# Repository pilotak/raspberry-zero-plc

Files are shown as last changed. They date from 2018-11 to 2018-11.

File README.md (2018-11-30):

# Raspberry Pi Zero/W based PLC
DIN mount PLC with following features
- power supply 7-45V DC
- 2x SPDT relay
- 1x SSR relay output (positive)
- 4x mosfet output (negative)
- 4x opto-isolated digital inputs with hardware debounce
- 3x analog input + 1 additional for power supply monitoring
- 1x CAN interface
- 1x RS232 (can be used for console or as standalone serial port)

## Picture
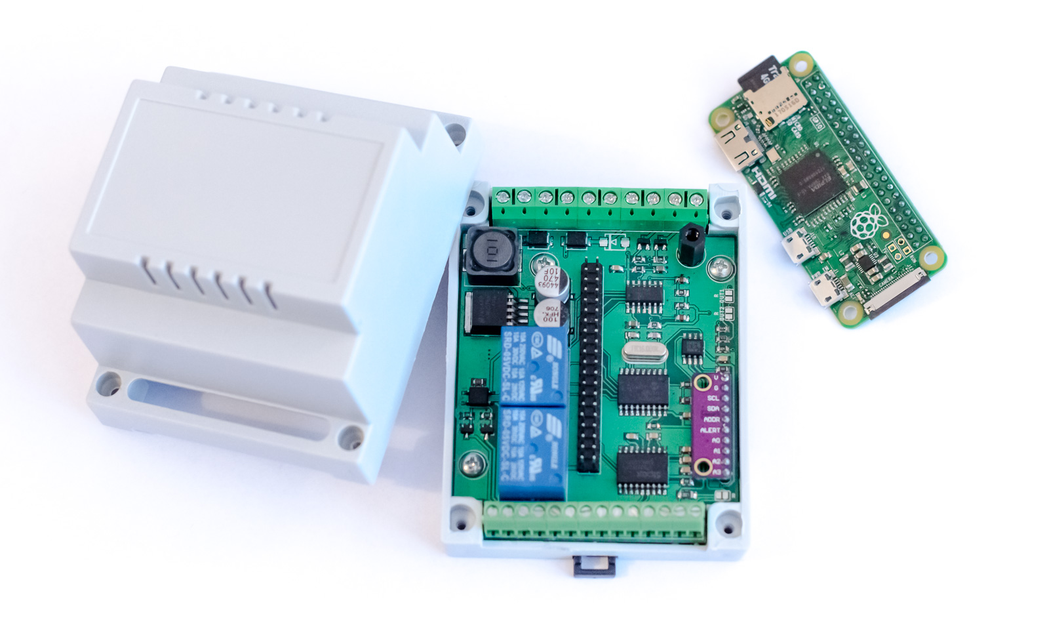
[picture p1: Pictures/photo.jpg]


## BOM

| Qty | Component | Value | Package |
|:---:| --- | ----- | --- |
| 4 | Capacitor | 1uF/6.3V | C0805 |
| 2 | Capacitor | 10uF/6.3V | C0805 |
| 2 | Capacitor | 22p | C0805 |
| 12 | Capacitor | 100n | C0805 |
| 1 | Capacitor | 100uF/50V | PANASONIC_E |
| 1 | Capacitor | 470uF/10V | PANASONIC_E |
| 6 | Diode | S1B | DO214AC (SMA) |
| 1 | TVS | SMBJ33 | DO214AA (SMB) |
| 2 | Shottky diode| SS26 | DO214AA (SMB) |
| 1 | NAND Schmitt trigger | 74HC132D | SO14 |
| 1 | CAN controller | MCP2515-I/SO | SO-18L |
| 1 | RS232 driver | SP3222EET | SO-18L |
| 1 | CAN transceiver | TJA1050 | SO08 |
| 4 | Photocoupler | TLP185 | SOP04 |
| 1 | SSR relay | AQY212S | SOP04 |
| 2 | Realy | SRD-5VDC-SL-C | |
| 1 | Inductor | DE1207-100 | DR125 |
| 4 | N-mosfet | 2N7002 | SOT23 |
| 1 | Crystal | 16MHz | HC49U-V |
| 2 | PNP transistor | BCX71SMD | SOT23 |
| 1 | P-mosfet | DMG2305UX | SOT23 |
| 2 | N-mosfet | IRLML0060TRPBF | SOT23 |
| 5 | Resistor| 1K | R0805 |
| 5 | Resistor| 2K2 | R0805 |
| 4 | Resistor| 10K | R0805 |
| 1 | Resistor| 18K | R0805 |
| 3 | Resistor| 47K | R0805 |
| 4 | Resistor| 68K | R0805 |
| 6 | Resistor| 100K | R0805 |
| 1 | Resistor| 120R | R1206 |
| 4 | Resistor| 820K | R0805 |
| 1 | ADC | ADS1015 | module |
| 1 | LDO regulator | LM1117-3.3 | SOT223 |
| 1 | Step-down regulator | LM2576-5.0 | TO-263-5 |
| 1 | Raspberry Pi | Zero | |
| 2 | Screw terminal| KF301-5.0-2P | KF301-5.0-2P |
| 2 | Screw terminal| KF301-5.0-3P | KF301-5.0-3P |
| 7 | Screw terminal| KF350-3.5-2P | KF350-3.50-2P |
| 1 | DIN case | Z100J PS | |

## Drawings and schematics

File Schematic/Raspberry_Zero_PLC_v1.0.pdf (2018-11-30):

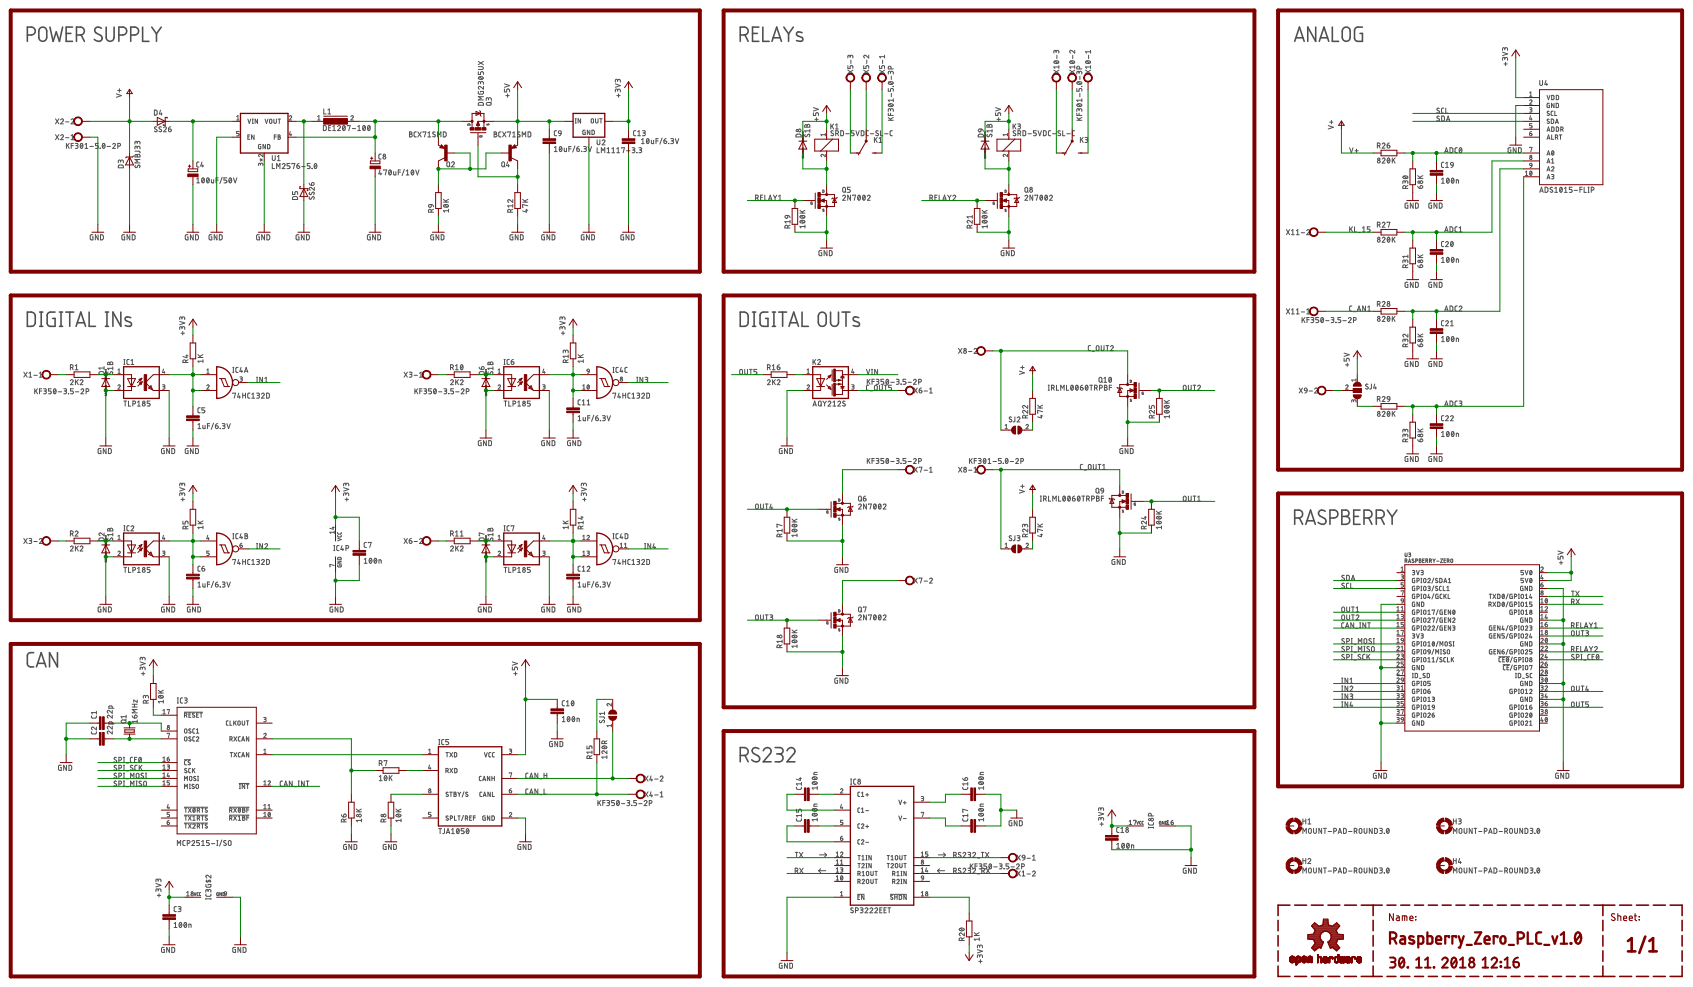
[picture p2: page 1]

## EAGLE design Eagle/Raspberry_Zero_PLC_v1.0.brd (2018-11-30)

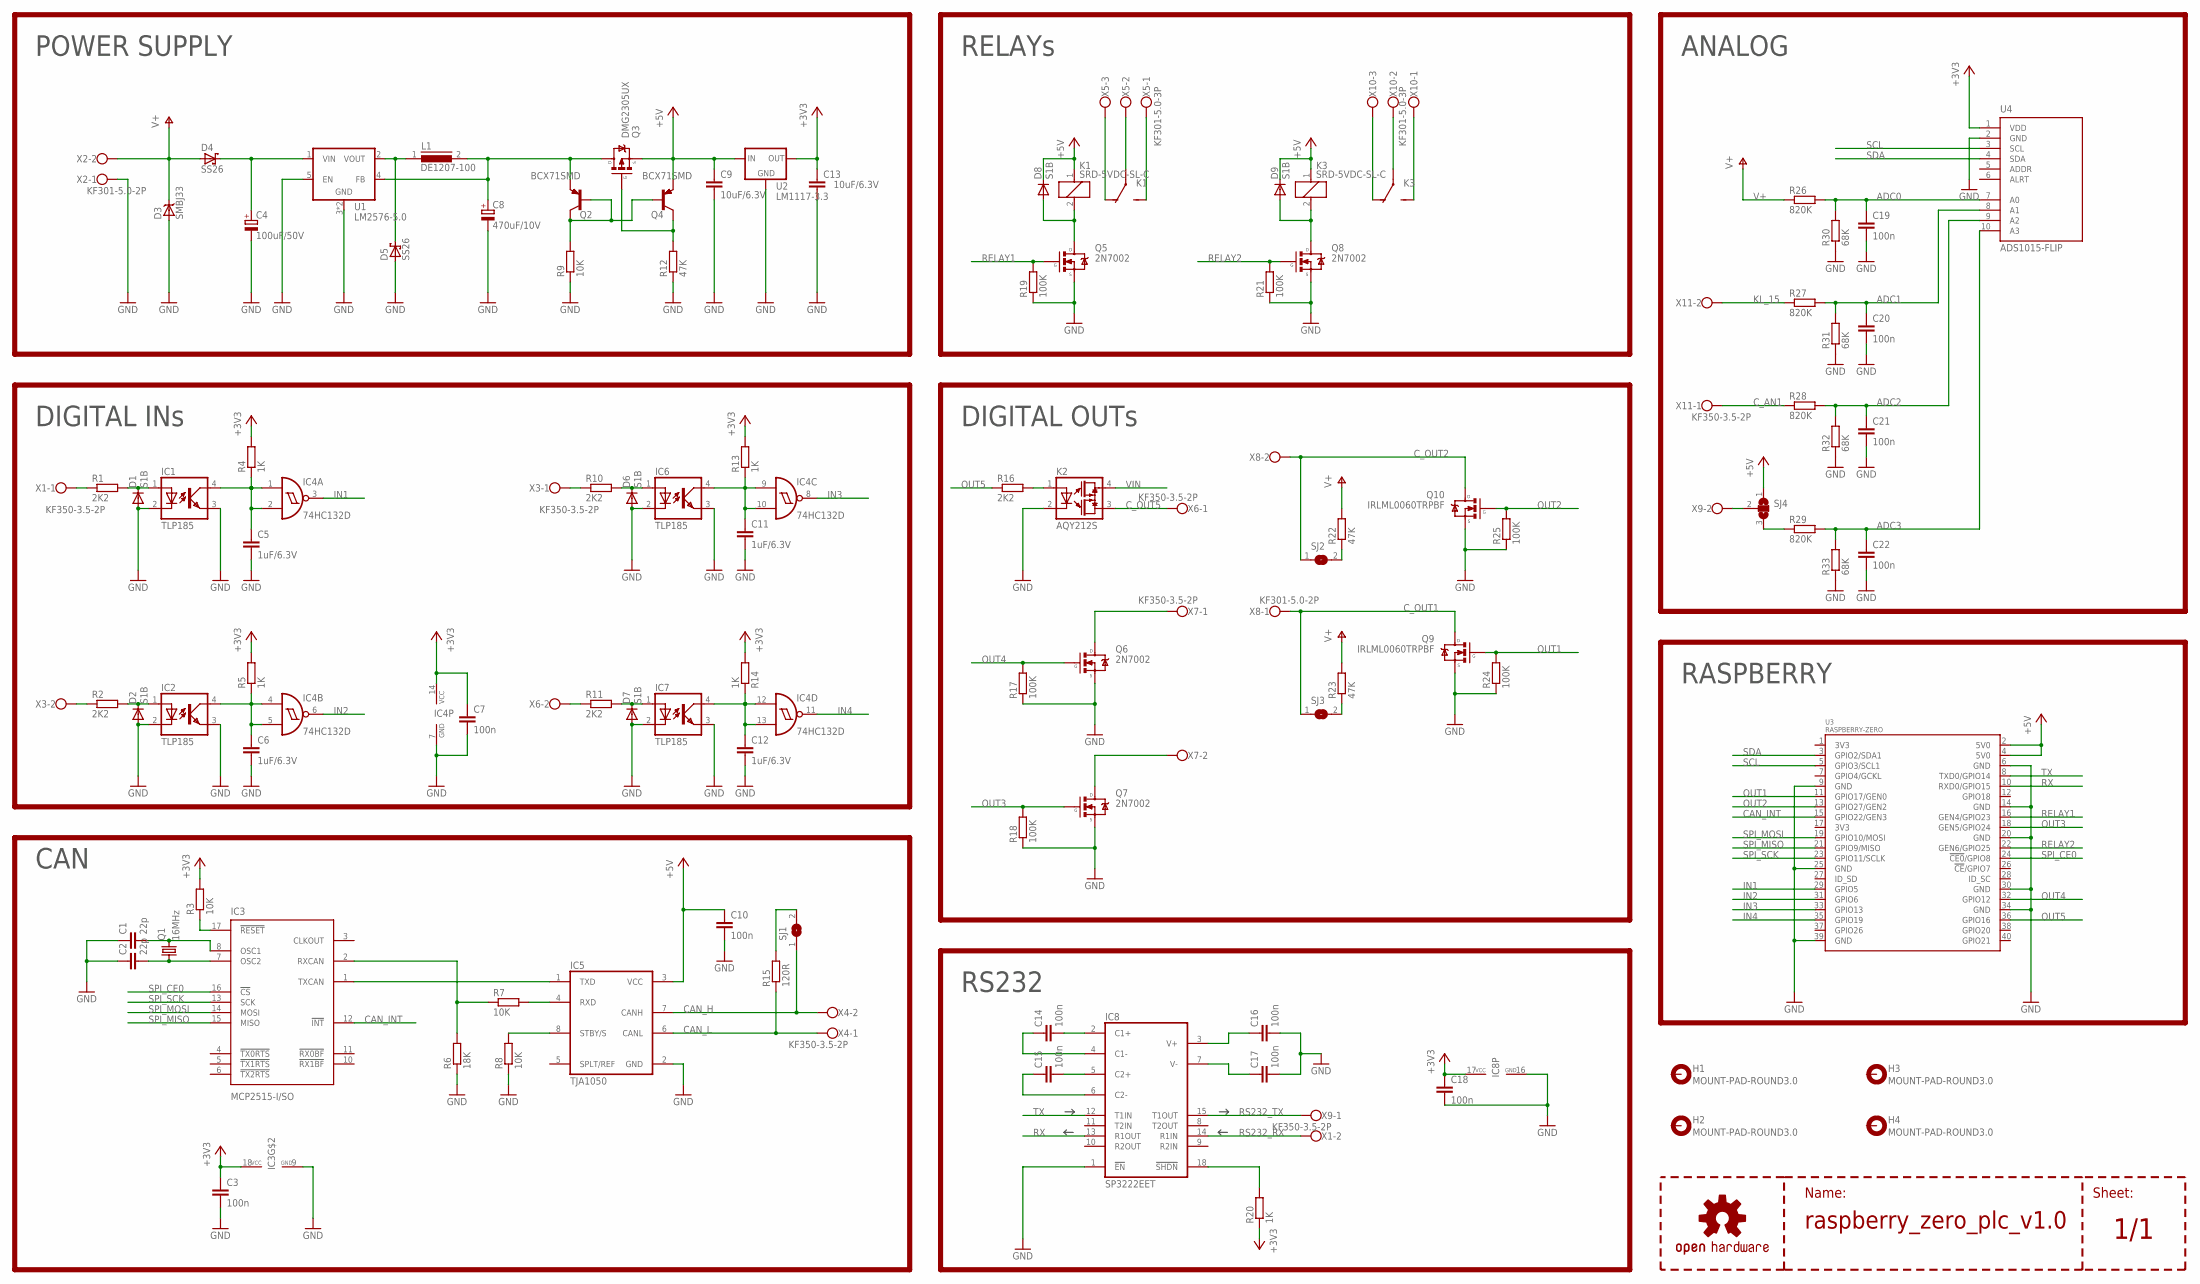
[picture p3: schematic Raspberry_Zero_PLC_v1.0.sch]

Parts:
C1, C2: 22p; C0805
C3, C7, C10, C14, C15, C16, C17, C18, C19, C20, C21, C22: 100n; C0805
C4: 100uF/50V; PANASONIC_E
C5, C6, C11, C12: 1uF/6.3V; C0805
C8: 470uF/10V; PANASONIC_E
C9, C13: 10uF/6.3V; C0805
D1, D2, D6, D7, D8, D9: S1B; DO214AC
D3: SMBJ33; DO214AA
D4, D5: SS26; DO214AA
H1, H2, H3, H4: MOUNT-PAD-ROUND3.0; 3,0-PAD
IC1, IC2, IC6, IC7: TLP185; SOP04
IC3: MCP2515-I/SO; SO-18L
IC4: 74HC132D; SO14
IC5: TJA1050; SO08
IC8: SP3222EET; SO-18L
K1, K3: SRD-5VDC-SL-C; SRD
K2: AQY212S; SOP04
L1: DE1207-100; DR125
LOGO1: OSHW-LOGOM-COPPER; OSHW-LOGO-M_COPPER
Q1: 16MHz; HC49U-V
Q2, Q4: BCX71SMD; SOT23
Q3: DMG2305UX; SOT23
Q5, Q6, Q7, Q8: 2N7002; SOT23
Q9, Q10: IRLML0060TRPBF; SOT23
R1, R2, R10, R11, R16: 2K2; R0805
R3, R7, R8, R9: 10K; R0805
R4, R5, R13, R14, R20: 1K; R0805
R6: 18K; R0805
R12, R22, R23: 47K; R0805
R15: 120R; R1206
R17, R18, R19, R21, R24, R25: 100K; R0805
R26, R27, R28, R29: 820K; R0805
R30, R31, R32, R33: 68K; R0805
SJ1, SJ2, SJ3: SJ
SJ4: SJ2W; SJ_2
U1: LM2576-5.0; TO-263-5
U2: LM1117-3.3; SOT223
U3: RASPBERRY-ZERO; RASPBERRYPI_ZERO
U4: ADS1015-FLIP; ADS1115-_FLIP
X1, X3, X4, X6, X7, X9, X11: KF350-3.5-2P; KF350-3.50-2P
X2, X8: KF301-5.0-2P
X5, X10: KF301-5.0-3P

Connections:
+3V3: C3.1, C7.1, C13.1, C18.1, IC3.18 (VCC), IC4.14 (VCC), IC8.17 (VCC), R3.2, R4.2, R5.2, R13.2, R14.2, R20.1, U2.2 (OUT), U2.4 (OUT), U4.1 (VDD)
+5V: C9.1, C10.1, D8.C, D9.C, IC5.3 (VCC), K1.1, K3.1, Q3.2 (S), Q4.2 (E), SJ4.1, U2.3 (IN), U3.2 (5V0), U3.4 (5V0)
ADC0: C19.1, R26.2, R30.2, U4.7 (A0)
ADC1: C20.1, R27.2, R31.2, U4.8 (A1)
ADC2: C21.1, R28.2, R32.2, U4.9 (A2)
ADC3: C22.1, R29.2, R33.2, U4.10 (A3)
CAN_H: IC5.7 (CANH), SJ1.1, X4.2
CAN_INT: IC3.12 (!INT!), U3.15 (GPIO22/GEN3)
CAN_L: IC5.6 (CANL), R15.1, X4.1
C_AN1: R28.1, X11.1
C_AN2/5V: SJ4.2, X9.2
C_IN1: R1.1, X1.1
C_IN2: R2.1, X3.2
C_IN3: R10.1, X3.1
C_IN4: R11.1, X6.2
C_OUT1: Q9.3 (D), SJ3.1, X8.1
C_OUT2: Q10.3 (D), SJ2.1, X8.2
C_OUT3: Q7.3 (D), X7.2
C_OUT4: Q6.3 (D), X7.1
C_OUT5: K2.3 (OUT0), X6.1
GND: C1.1, C2.1, C3.2, C4.-, C5.2, C6.2, C7.2, C8.-, C9.2, C10.2, C11.2, C12.2, C13.2, C16.2, C17.2, C18.2, C19.2, C20.2, C21.2, C22.2, D1.A, D2.A, D3.A, D5.A, D6.A, D7.A, IC1.2 (C), IC1.3 (EMIT), IC2.2 (C), IC2.3 (EMIT), IC3.9 (GND), IC4.7 (GND), IC5.2 (GND), IC6.2 (C), IC6.3 (EMIT), IC7.2 (C), IC7.3 (EMIT), IC8.1 (!EN!), IC8.16 (GND), K2.2 (C), Q5.2 (S), Q6.2 (S), Q7.2 (S), Q8.2 (S), Q9.2 (S), Q10.2 (S), R6.1, R8.1, R9.1, R12.1, R17.1, R18.1, R19.1, R21.1, R24.1, R25.1, R30.1, R31.1, R32.1, R33.1, U1.3 (GND), U1.5 (EN), U1.6 (GND), U2.1 (GND), U3.6 (GND), U3.9 (GND), U3.14 (GND), U3.20 (GND), U3.25 (GND), U3.30 (GND), U3.34 (GND), U3.39 (GND), U4.2 (GND), X2.1
IN1: IC4.3 (O), U3.29 (GPIO5)
IN2: IC4.6 (O), U3.31 (GPIO6)
IN3: IC4.8 (O), U3.33 (GPIO13)
IN4: IC4.11 (O), U3.35 (GPIO19)
KL_15: R27.1, X11.2
unnamed: Q2.1 (B), Q2.3 (C), Q4.1 (B), R9.2
unnamed: Q3.1 (G), Q4.3 (C), R12.2
unnamed: C2.2, IC3.7 (OSC2), Q1.1
unnamed: C8.+, L1.2, Q2.2 (E), Q3.3 (D), U1.4 (FB)
unnamed: C1.2, IC3.8 (OSC1), Q1.2
unnamed: IC3.1 (TXCAN), IC5.1 (TXD)
unnamed: IC3.2 (RXCAN), R6.2, R7.1
unnamed: IC5.8 (STBY/S), R8.2
unnamed: D5.C, L1.1, U1.2 (VOUT)
unnamed: IC5.4 (RXD), R7.2
unnamed: IC3.17 (!RESET!), R3.1
unnamed: D6.C, IC6.1 (A), R10.2
unnamed: C16.1, IC8.3 (V+)
unnamed: C17.1, IC8.7 (V-)
unnamed: D9.A, K3.2, Q8.3 (D)
unnamed: D8.A, K1.2, Q5.3 (D)
unnamed: C15.2, IC8.5 (C2+)
unnamed: C15.1, IC8.6 (C2-)
unnamed: C14.1, IC8.4 (C1-)
unnamed: C14.2, IC8.2 (C1+)
unnamed: R29.1, SJ4.3
unnamed: D1.C, IC1.1 (A), R1.2
unnamed: D2.C, IC2.1 (A), R2.2
unnamed: R22.1, SJ2.2
unnamed: R23.1, SJ3.2
unnamed: K2.1 (A), R16.2
unnamed: C5.1, IC1.4 (COL), IC4.1 (I0), IC4.2 (I1), R4.1
unnamed: C11.1, IC4.9 (I0), IC4.10 (I1), IC6.4 (COL), R13.1
unnamed: C6.1, IC2.4 (COL), IC4.4 (I0), IC4.5 (I1), R5.1
unnamed: C12.1, IC4.12 (I0), IC4.13 (I1), IC7.4 (COL), R14.1
unnamed: R15.2, SJ1.2
unnamed: IC8.18 (!SHDN!), R20.2
unnamed: D7.C, IC7.1 (A), R11.2
OUT1: Q9.1 (G), R24.2, U3.11 (GPIO17/GEN0)
OUT2: Q10.1 (G), R25.2, U3.13 (GPIO27/GEN2)
OUT3: Q7.1 (G), R18.2, U3.18 (GEN5/GPIO24)
OUT4: Q6.1 (G), R17.2, U3.32 (GPIO12)
OUT5: R16.1, U3.36 (GPIO16)
RELAY1: Q5.1 (G), R19.2, U3.16 (GEN4/GPIO23)
RELAY1_COM: K1.COM, X5.2
RELAY1_NC: K1.NC, X5.3
RELAY1_NO: K1.NO, X5.1
RELAY2: Q8.1 (G), R21.2, U3.22 (GEN6/GPIO25)
RELAY2_COM: K3.COM, X10.2
RELAY2_NC: K3.NC, X10.3
RELAY2_NO: K3.NO, X10.1
RS232_RX: IC8.14 (R1IN), X1.2
RS232_TX: IC8.15 (T1OUT), X9.1
RX: IC8.13 (R1OUT), U3.10 (RXD0/GPIO15)
SCL: U3.5 (GPIO3/SCL1), U4.3 (SCL)
SDA: U3.3 (GPIO2/SDA1), U4.4 (SDA)
SPI_CE0: IC3.16 (!CS!), U3.24 (!CE0!/GPIO8)
SPI_MISO: IC3.15 (MISO), U3.21 (GPIO9/MISO)
SPI_MOSI: IC3.14 (MOSI), U3.19 (GPIO10/MOSI)
SPI_SCK: IC3.13 (SCK), U3.23 (GPIO11/SCLK)
TX: IC8.12 (T1IN), U3.8 (TXD0/GPIO14)
V+: D3.C, D4.A, R22.2, R23.2, R26.1, X2.2
VIN: C4.+, D4.C, K2.4 (OUT1), U1.1 (VIN)

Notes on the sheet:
DIGITAL INs
DIGITAL OUTs
ANALOG
RS232
RASPBERRY
POWER SUPPLY
CAN
RELAYs
Sheet:
Name:

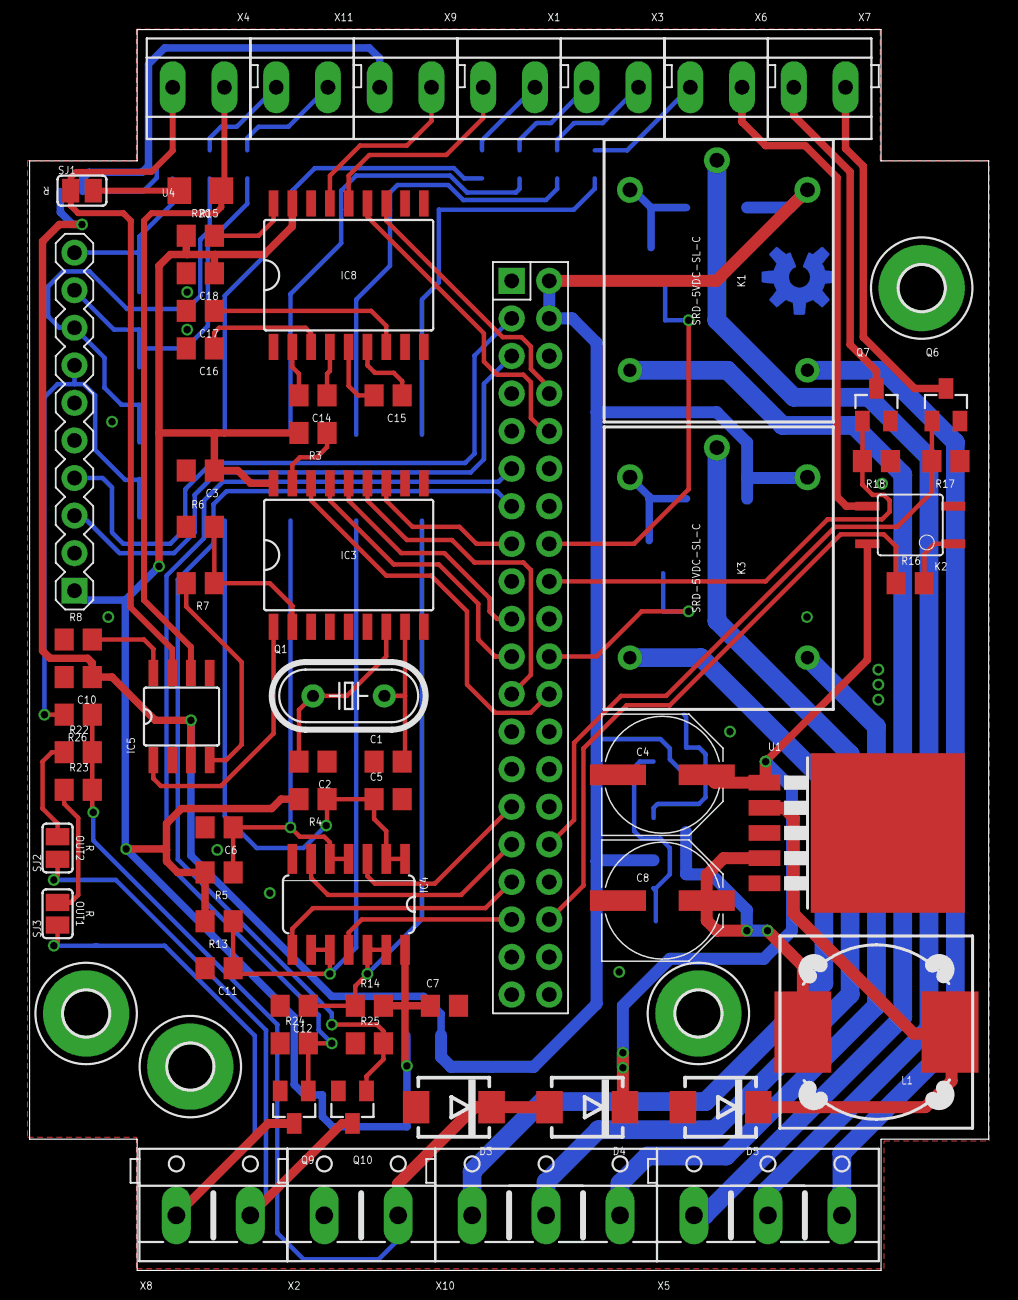
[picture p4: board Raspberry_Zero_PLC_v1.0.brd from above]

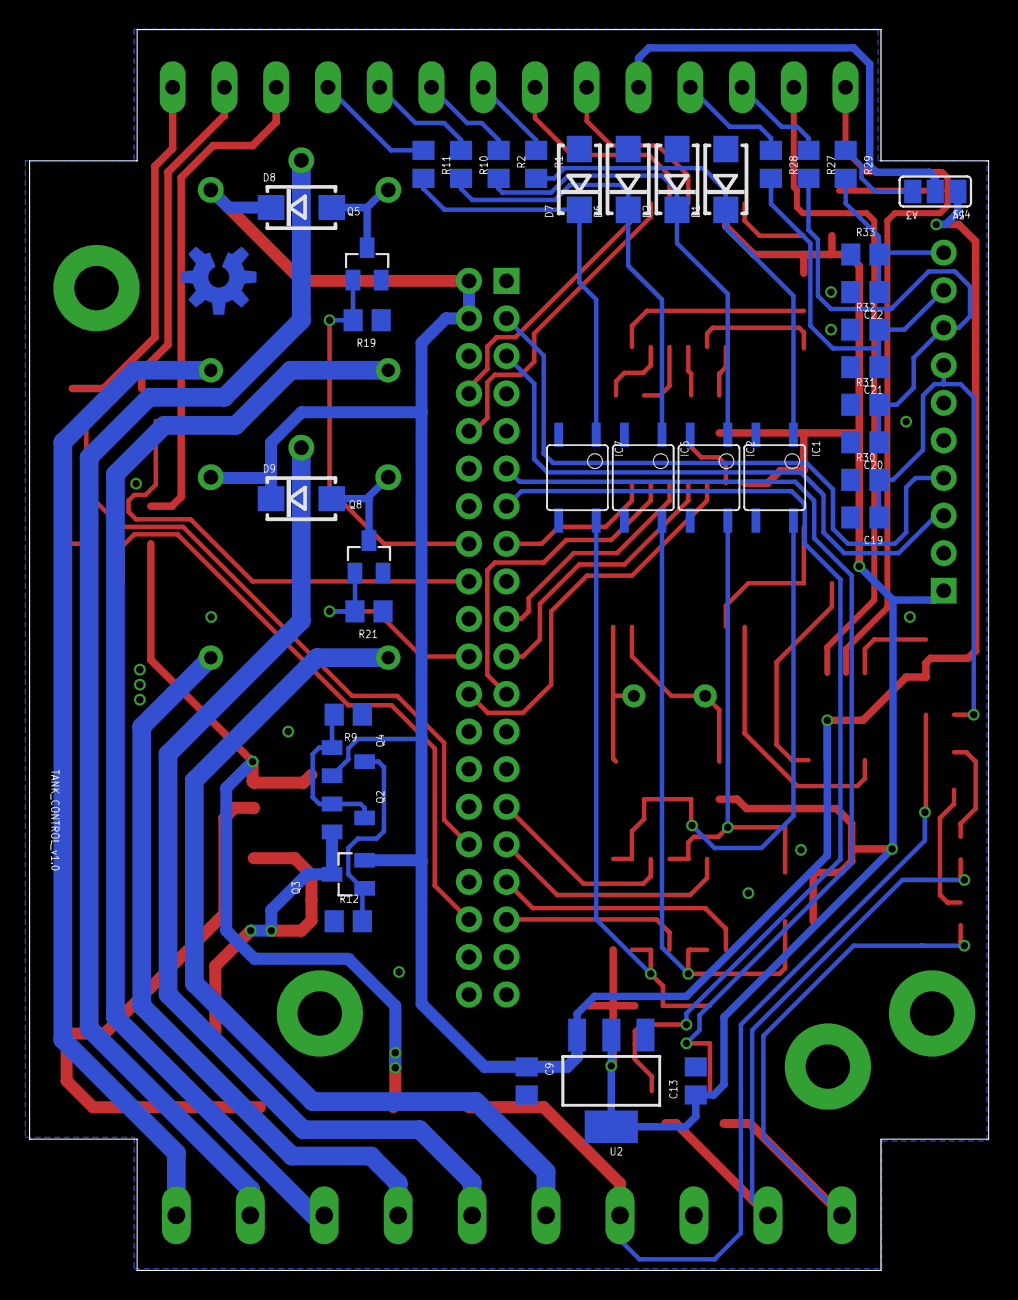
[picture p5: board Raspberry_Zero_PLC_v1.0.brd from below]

Board: 2 copper layers, 64.9 x 83.9 mm, 110 parts (39 on the bottom side), 84 nets.

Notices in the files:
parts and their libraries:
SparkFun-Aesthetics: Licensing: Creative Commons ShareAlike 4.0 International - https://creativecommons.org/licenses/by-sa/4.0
